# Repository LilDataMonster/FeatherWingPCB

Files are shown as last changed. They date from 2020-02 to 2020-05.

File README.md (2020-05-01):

The `FeatherWing_KC5` directory of this repository contains a
[KiCad][1] 5 [template][4] for making [FeatherWing][2] boards.

Since Adafruit does not provide standardized names for the GPIO pins,
I found these online.

The PCB has been printed and fits with Feathers.

## License

This repository is licensed under [the same terms as the KiCad
libraries][9], which is the [CC-BY-SA 4.0][10] license, with an
exception that says that electronic designs based on this repository
are not bound by the attribution and share-alike conditions.

[1]: http://kicad-pcb.org/
[2]: https://learn.adafruit.com/adafruit-feather/feather-specification
[3]: https://funwithsoftware.org/posts/2018-08-31-feather-ascii-art-pinout.html
[4]: http://docs.kicad-pcb.org/5.1.2/en/kicad/kicad.html#project_templates
[9]: https://forum.kicad.info/t/kicad-library-licensing/7856
[10]: https://creativecommons.org/licenses/by-sa/4.0/legalcode
# FeatherWingPCB

Allows up to 10 DS18B20 temperature sensors to be connected to a Feather via A0.

Assumes use of 2.54mm terminal blocks as well as a 4.7k resistor

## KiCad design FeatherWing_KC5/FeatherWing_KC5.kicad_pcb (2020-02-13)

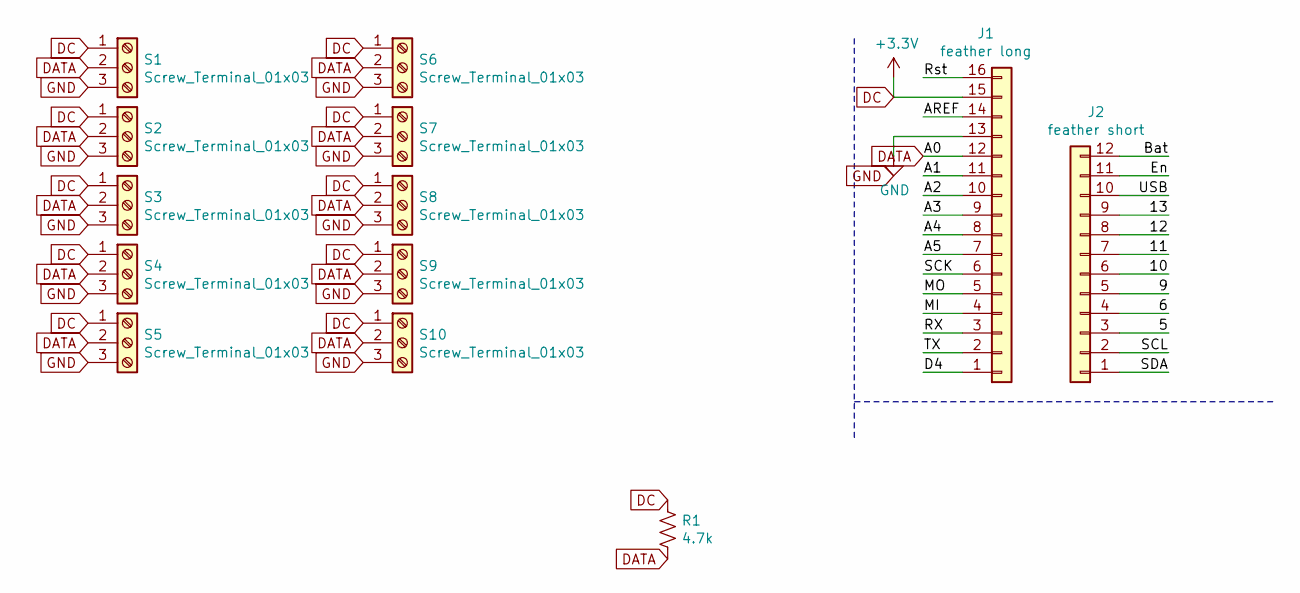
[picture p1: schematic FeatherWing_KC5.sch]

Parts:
J1: feather long; PinHeader_1x16_P2.54mm_Vertical
J2: feather short; PinHeader_1x12_P2.54mm_Vertical
R1: 4.7k; R_Axial_DIN0207_L6.3mm_D2.5mm_P7.62mm_Horizontal
S1, S2, S3, S4, S5, S6, S7, S8, S9, S10: Screw_Terminal_01x03; TerminalBlock_TE_282834-3_1x03_P2.54mm_Horizontal

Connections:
/5: J2.3
/6: J2.4
/9: J2.5
/10: J2.6
/11: J2.7
/12: J2.8
/13: J2.9
/A1: J1.11
/A2: J1.10
/A3: J1.9
/A4: J1.8
/A5: J1.7
/AREF: J1.14
/Bat: J2.12
/D4: J1.1
/En: J2.11
/MI: J1.4
/MO: J1.5
/RX: J1.3
/Rst: J1.16
/SCK: J1.6
/SCL: J2.2
/SDA: J2.1
/TX: J1.2
/USB: J2.10
DATA: J1.12, R1.2, S1.2, S2.2, S3.2, S4.2, S5.2, S6.2, S7.2, S8.2, S9.2, S10.2
DC: J1.15, R1.1, S1.1, S2.1, S3.1, S4.1, S5.1, S6.1, S7.1, S8.1, S9.1, S10.1
GND: J1.13, S1.3, S2.3, S3.3, S4.3, S5.3, S6.3, S7.3, S8.3, S9.3, S10.3

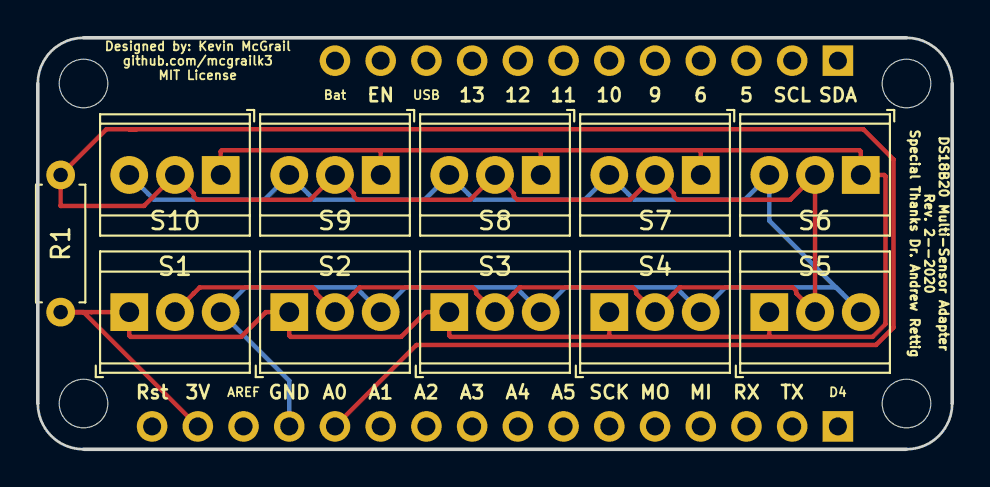
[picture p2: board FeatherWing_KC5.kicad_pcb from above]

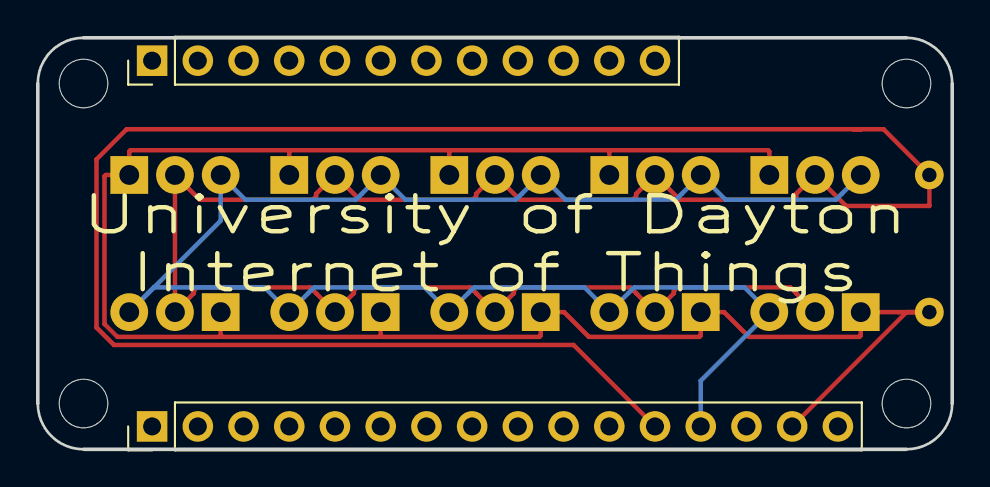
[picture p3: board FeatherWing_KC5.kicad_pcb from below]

Board: 2 copper layers, 50.8 x 22.9 mm, 13 parts (2 on the bottom side), 3 nets.

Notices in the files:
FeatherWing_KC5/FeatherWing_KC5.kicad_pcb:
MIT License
